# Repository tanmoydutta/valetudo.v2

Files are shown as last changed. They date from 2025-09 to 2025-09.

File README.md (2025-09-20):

# Valetudo V2 - a CR2032 powered Temperature and Humidity sensor with ePaper display
Valetudo V2 has been an improvement on the previous version to add an onboard SEN40 Temperature / Humidity Sensor. This design also includes adjustments to the Battery circuit as well as support for different variants of the ePaper Display.

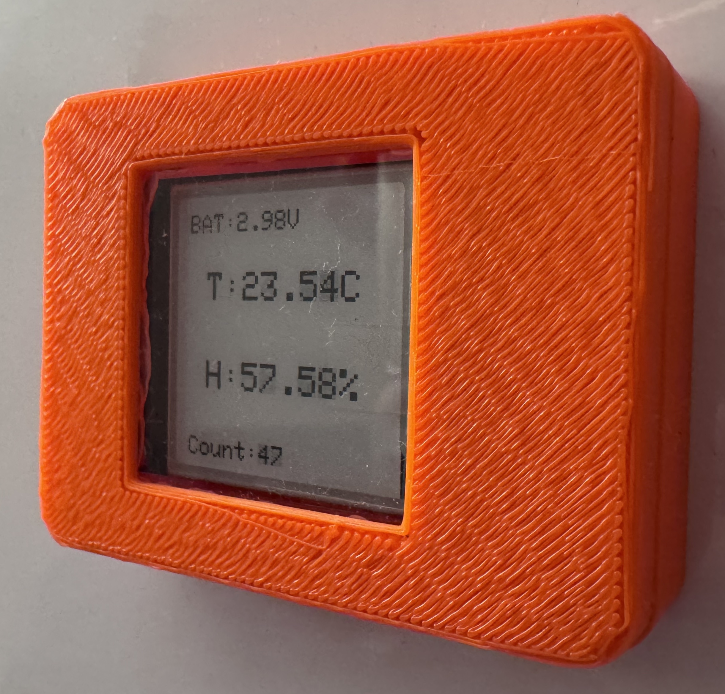
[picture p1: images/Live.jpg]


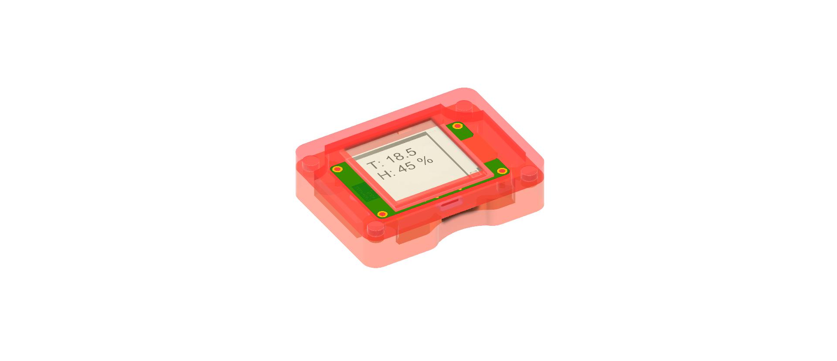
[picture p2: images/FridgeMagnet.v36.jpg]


The form factor has remained the same for the new PCB and some of the components have been slightly reoriented to make room for the new electronics. Powered by the same CR2032 coin cell with firmware enhancements to improve battery life.

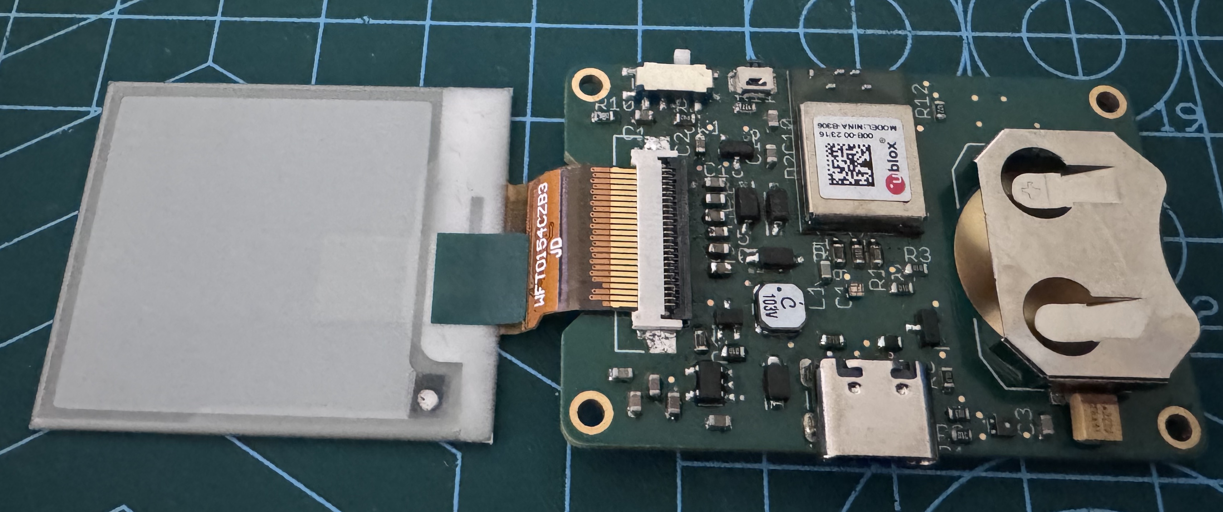
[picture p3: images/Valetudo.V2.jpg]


The body and the lid of the enclosure are embedded with magnetic snap-on feature with an acrylic viewing window for protection for the epaper display. 

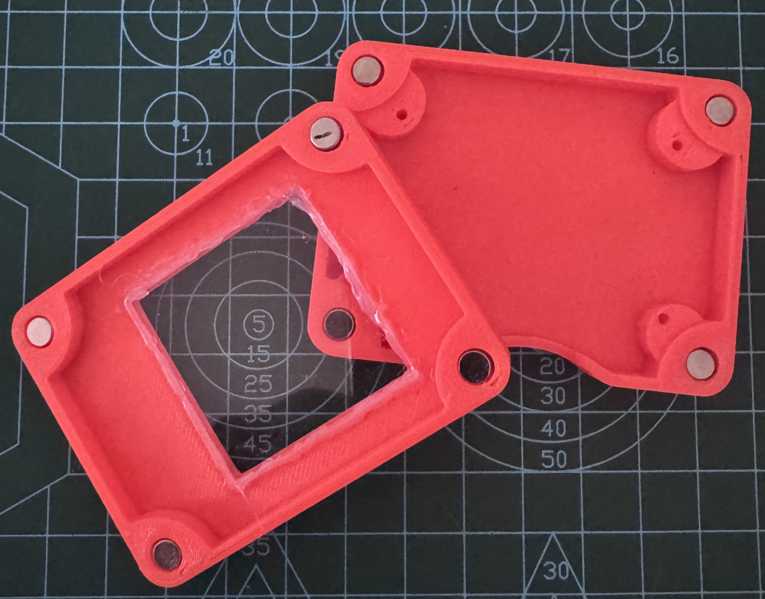
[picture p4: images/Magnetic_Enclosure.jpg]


The enclosure is now fitted with two large 12x3 mm neodymium magnets for better strength to remain stuck with a metallic surface like a refrigerator or a whiteboard.
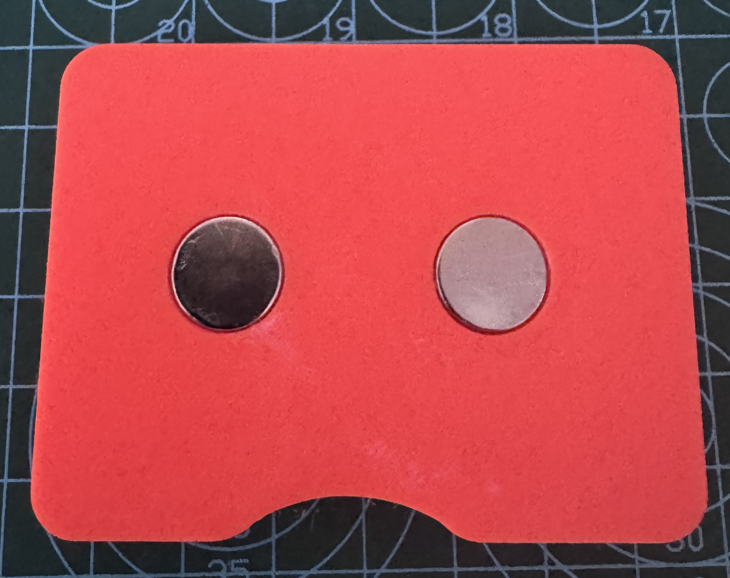
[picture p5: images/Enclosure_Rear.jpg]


This project is certified as Open Source Hardware - 
<p align="center">
  <a href="https://certification.oshwa.org/nl000034.html">
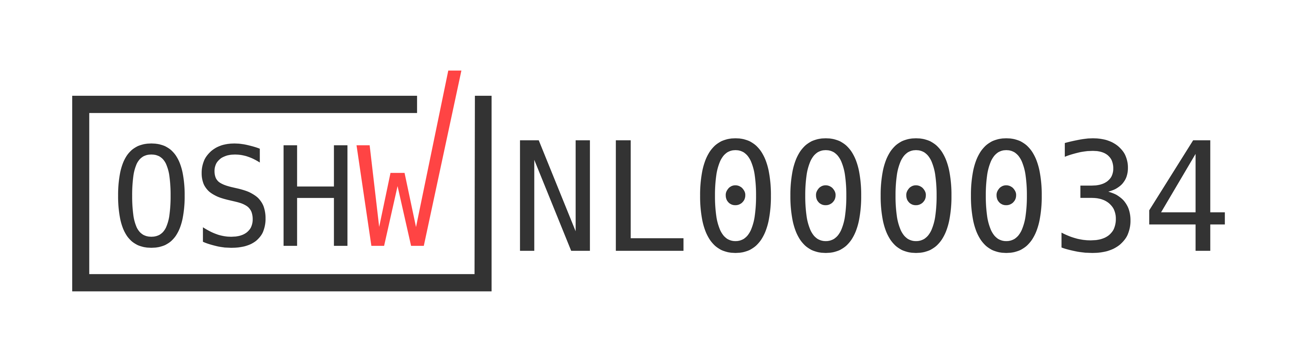
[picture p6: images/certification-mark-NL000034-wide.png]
OSHWA OSHWA Certification
    
  </a>
</p>

License information on the hardware and software and documentation is as follows -



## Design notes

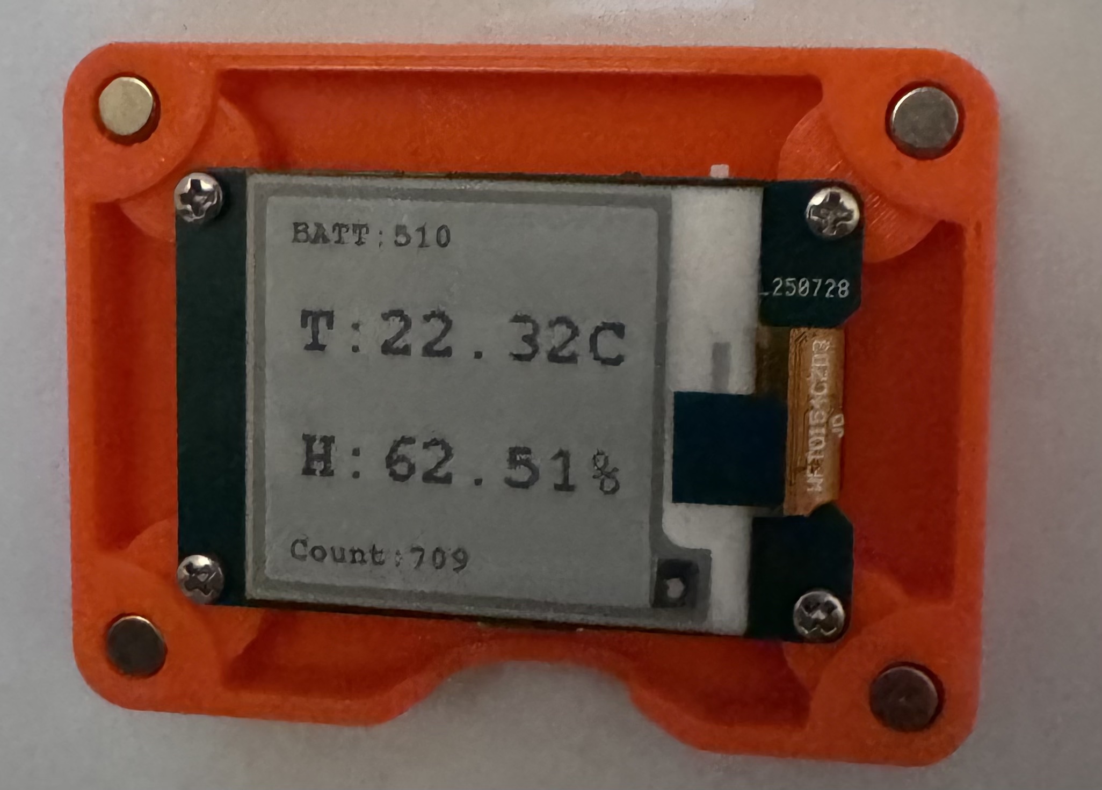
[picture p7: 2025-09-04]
images/InAction.jpg

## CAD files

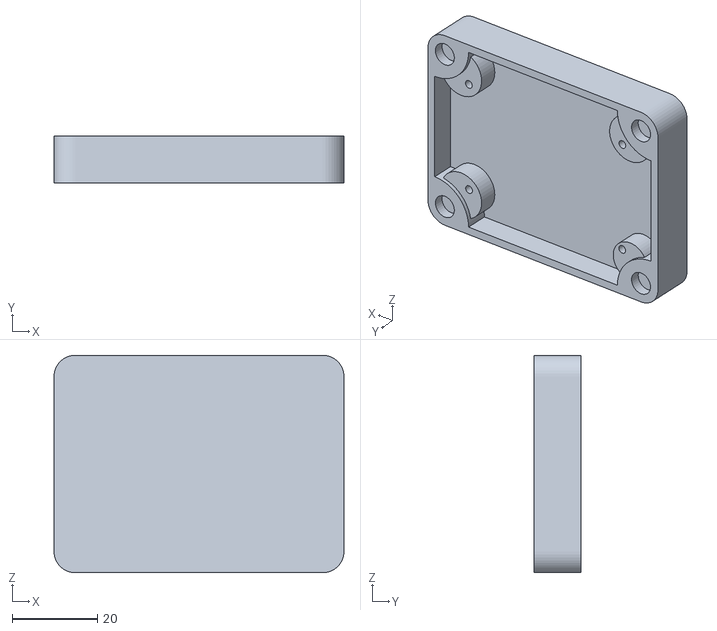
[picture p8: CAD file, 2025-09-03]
3D_Models/Magnetic_Bottom.stl
68.0 x 11.0 x 51.0

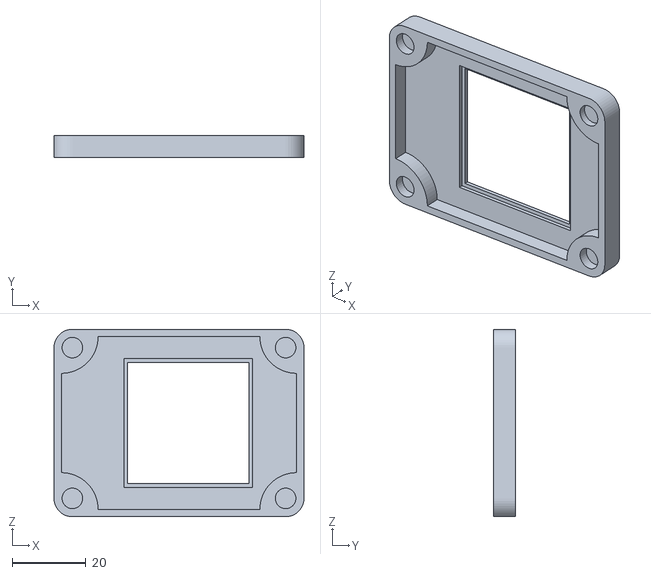
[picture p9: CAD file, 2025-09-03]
3D_Models/Magnetic_Top.stl
68.0 x 6.00 x 51.0

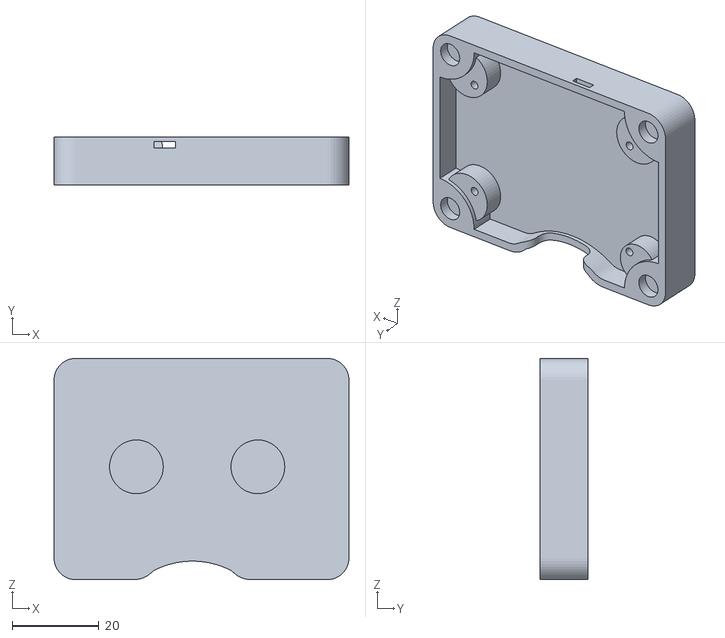
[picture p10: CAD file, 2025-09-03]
3D_Models/Magnetic_Bottom_Hollow_Bent.stl
68.0 x 11.0 x 51.0

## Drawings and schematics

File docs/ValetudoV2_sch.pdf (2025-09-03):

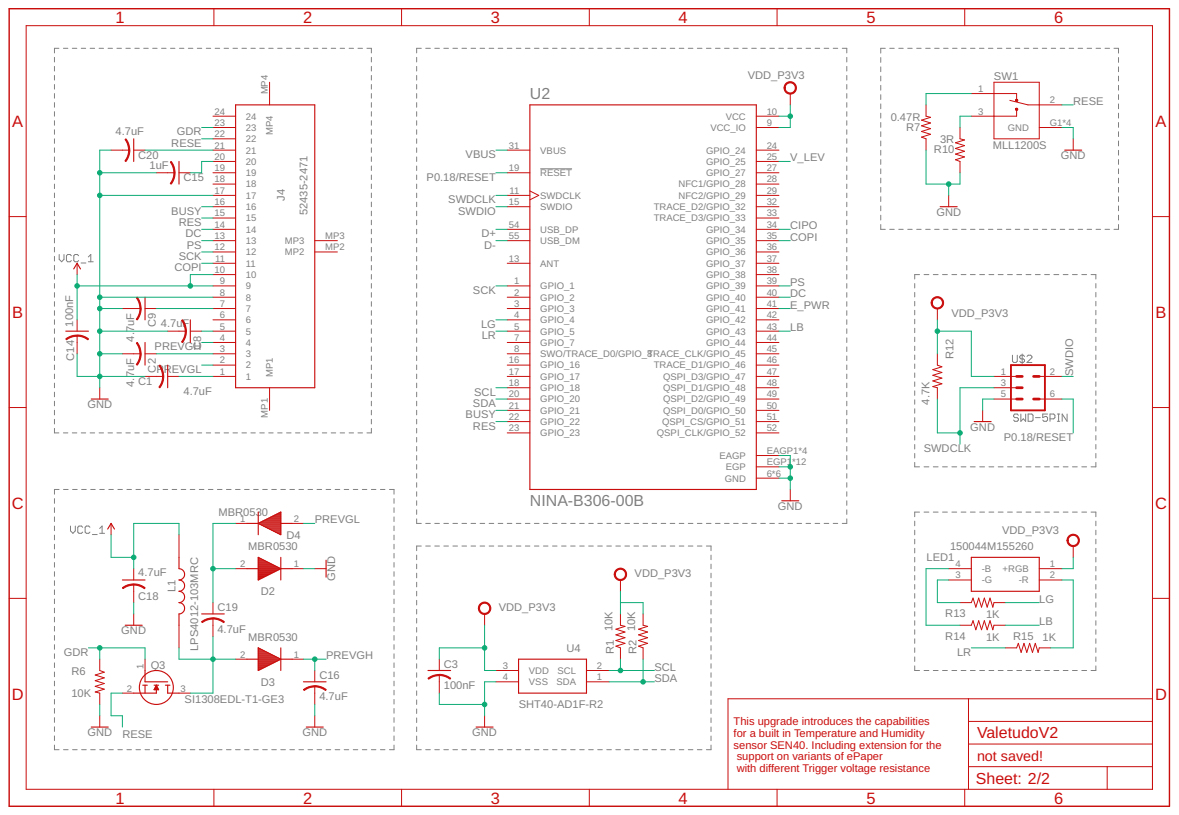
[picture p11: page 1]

This upgrade introduces the capabilities for a built in Temperature and Humidity sensor SEN40. Including extension for the

Sheet:

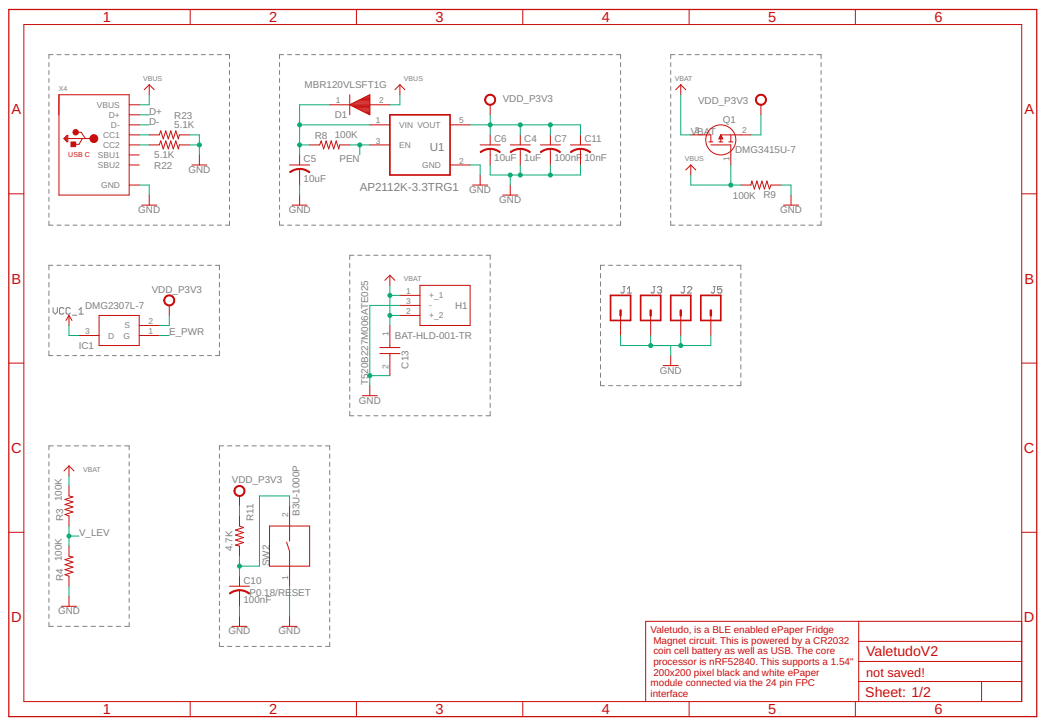
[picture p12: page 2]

Valetudo, is a BLE enabled ePaper Fridge Magnet circuit. This is powered by a CR2032 coin cell battery as well as USB. The core processor is nRF52840. This supports a 1.54" 200x200 pixel black and white ePaper module connected via the 24 pin FPC interface

Sheet: 1/2

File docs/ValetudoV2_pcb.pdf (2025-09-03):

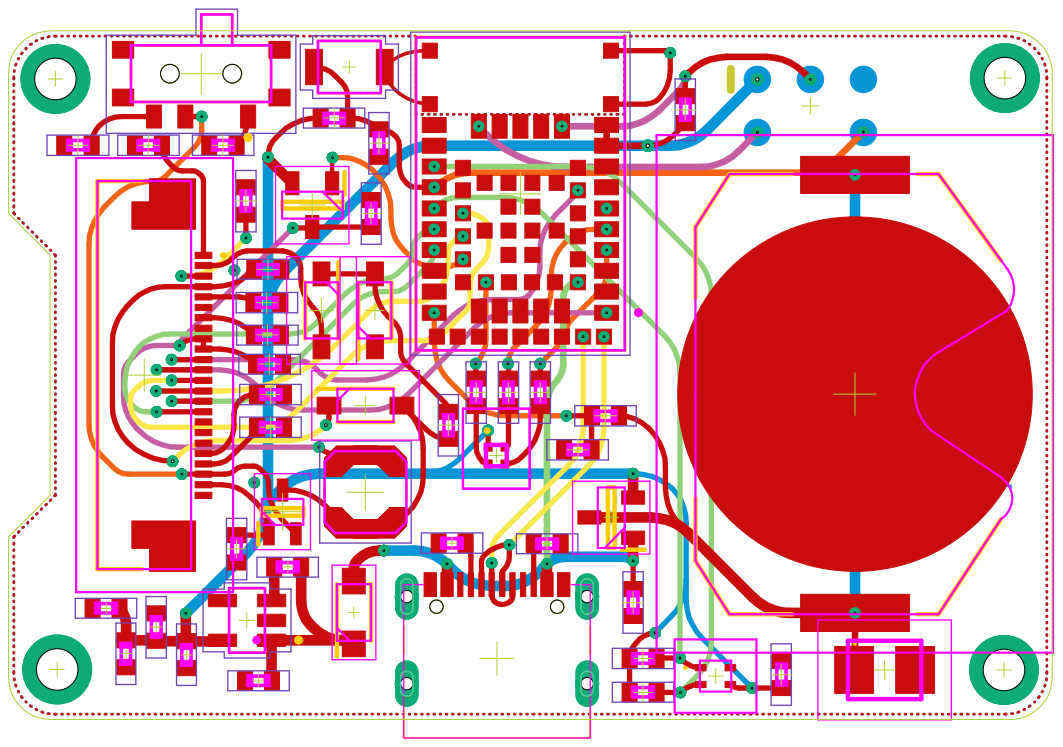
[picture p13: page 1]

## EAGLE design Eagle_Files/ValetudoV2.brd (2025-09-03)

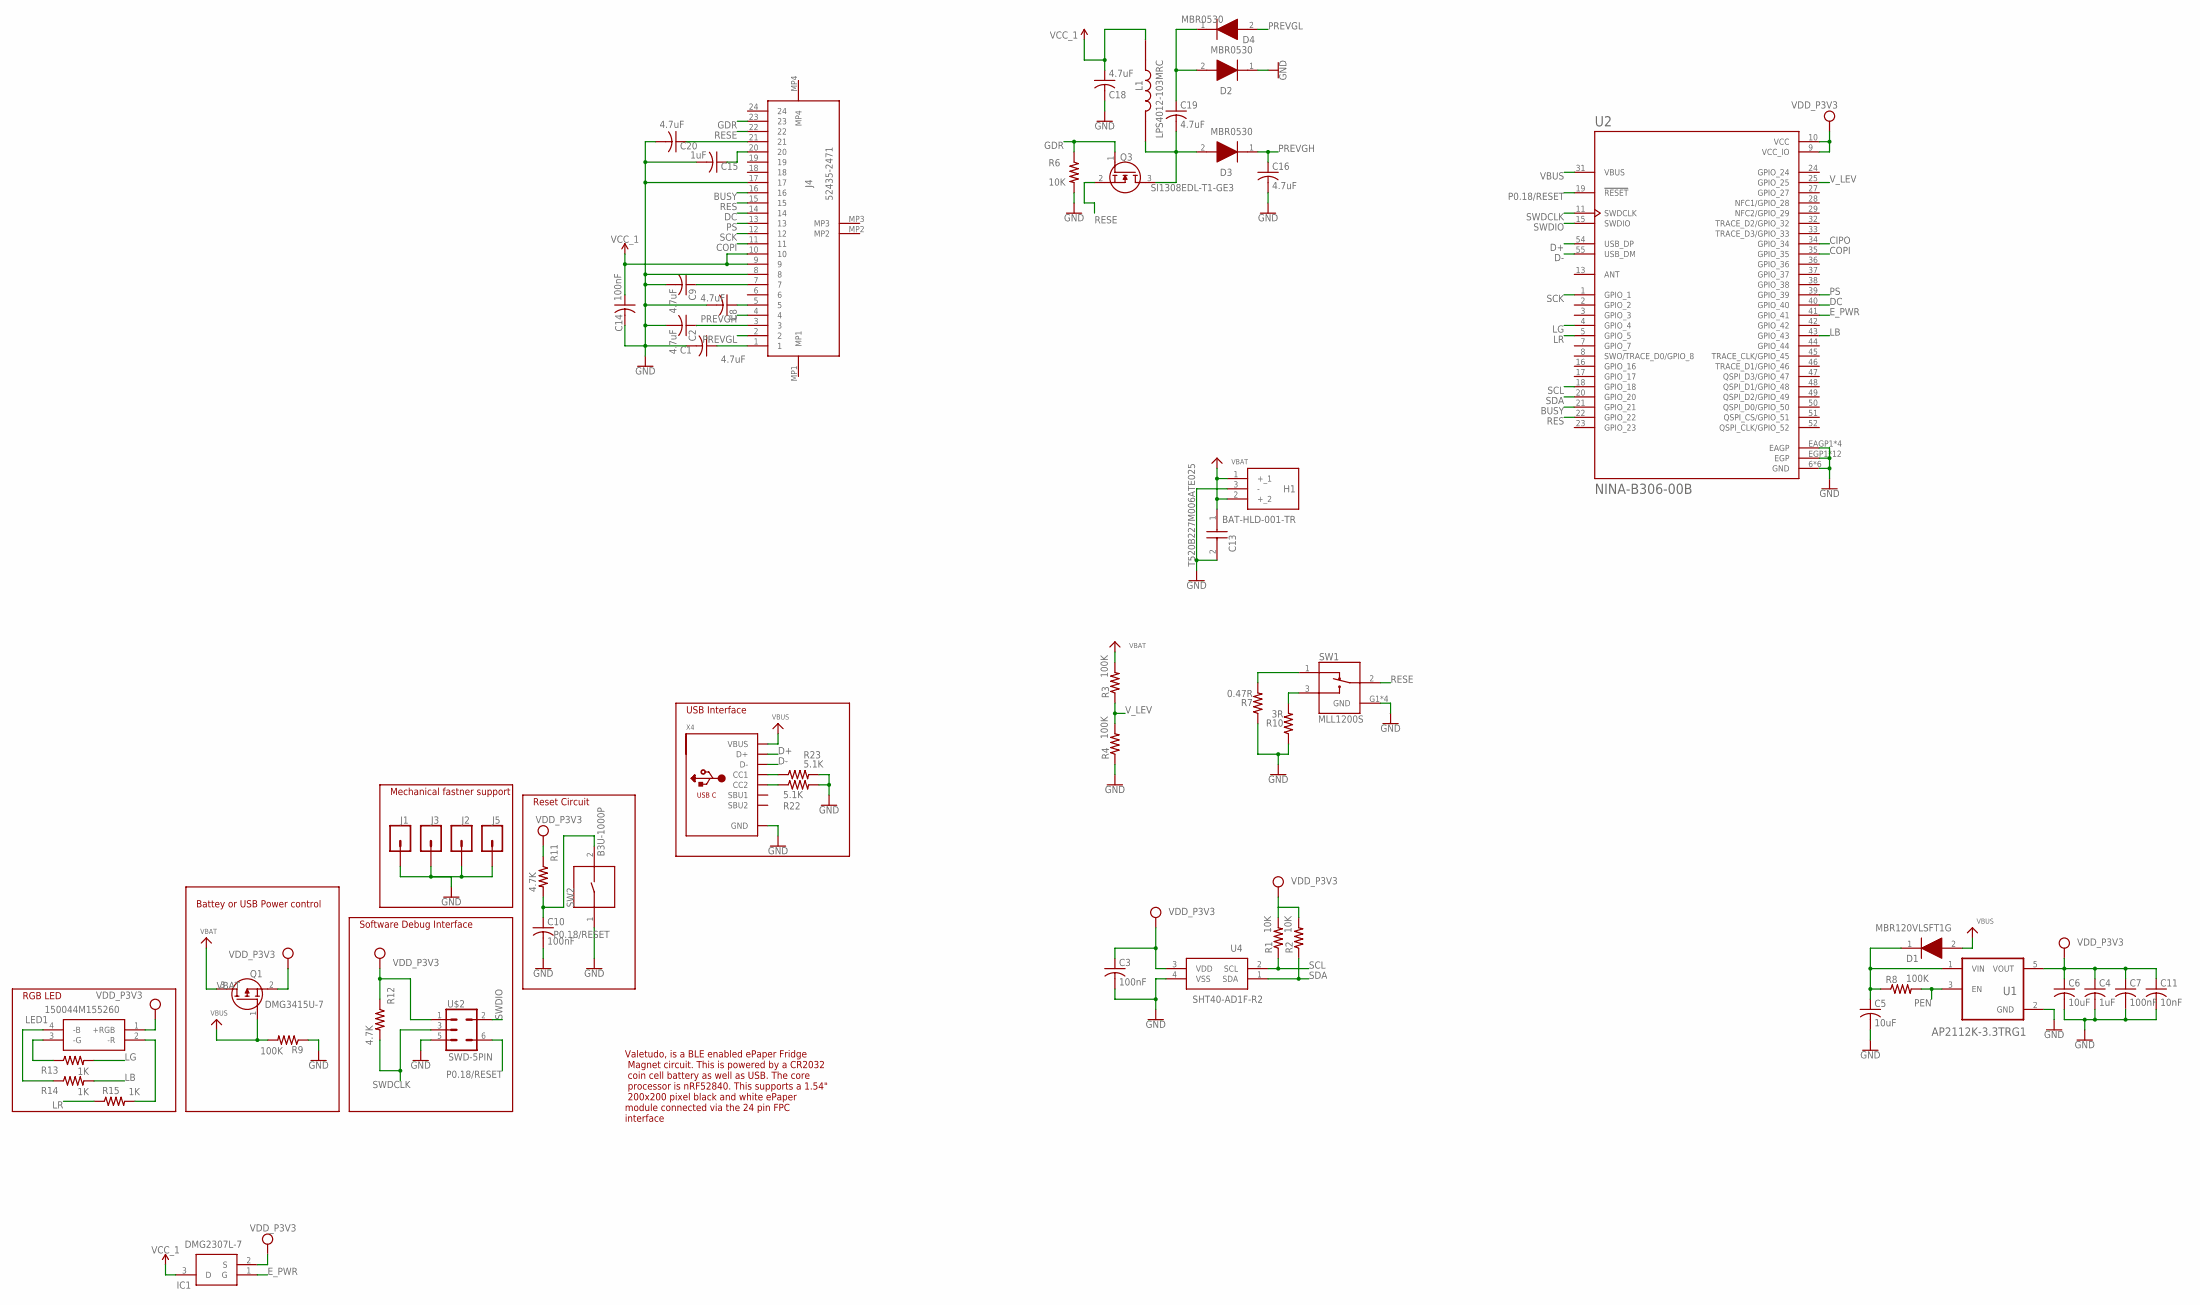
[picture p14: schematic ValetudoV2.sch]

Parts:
C1, C2, C8, C9, C16, C18, C19, C20: 4.7uF; C0402
C3, C7, C10, C14: 100nF; C0402
C4, C15: 1uF; C0402
C5, C6: 10uF; C0402
C11: 10nF; C0402
C13: T520B227M006ATE025; T520B
D1: MBR120VLSFT1G; SODFL3616X98N
D2, D3, D4: MBR0530; SOD3716X135N
H1: BAT-HLD-001-TR; BATHLD001TR
IC1: DMG2307L-7; SOT96P240X110-3N
J1, J2, J3, J5: CONN_01PTH_2MM; 1X01_2MM
J4: 52435-2471; 524352471
L1: LPS4012-103MRC; IND_LPS4012-103MRC
LED1: 150044M155260
Q1: DMG3415U-7; SOT96P240X100-3N
Q3: SI1308EDL-T1-GE3; SOT65P210X110-3N
R1, R2, R6: 10K; R0402
R3, R4, R8, R9: 100K; R0402
R7: 0.47R; R0402
R10: 3R; R0402
R11, R12: 4.7K; R0402
R13, R14, R15: 1K; R0402
R22, R23: 5.1K; R0402
SW1: MLL1200S; SW_MLL1200S
SW2: B3U-1000P; SW_B3U-1000P
U1: AP2112K-3.3TRG1; SOT95P285X140-5N
U2: NINA-B306-00B; XCVR_NINA-B306-00B
U4: SHT40-AD1F-R2; SHT40AD1FR2
U$2: SWD-5PIN; PAD_05_03X2_TP_NO4
X4: MICROBUILDER_USB_C; MICROBUILDER_USB_C_CUSB31-CFM2AX-01-X

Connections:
BUSY: J4.16, U2.21 (GPIO_21)
CIPO: U2.34 (GPIO_34)
COPI: J4.11, U2.35 (GPIO_35)
D+: U2.54 (USB_DP), X4.A6 (D+), X4.B6 (D+)
D-: U2.55 (USB_DM), X4.A7 (D-), X4.B7 (D-)
DC: J4.14, U2.40 (GPIO_40)
E_PWR: IC1.1 (G), U2.41 (GPIO_41)
GDR: J4.23, Q3.1 (G), R6.1
GND: C1.2, C2.2, C3.2, C4.2, C5.2, C6.2, C7.2, C8.2, C9.2, C10.2, C11.2, C13.2 (-), C14.2, C15.2, C16.2, C18.2, C20.2, D2.1 (K), H1.3 (-), J1.1, J2.1, J3.1, J4.8, J4.17, J5.1, R4.1, R6.2, R7.1, R9.1, R10.1, R22.2, R23.2, SW1.G1 (GND), SW1.G2 (GND), SW1.G3 (GND), SW1.G4 (GND), SW2.1, U1.2 (GND), U2.6 (GND), U2.12 (GND), U2.14 (GND), U2.26 (GND), U2.30 (GND), U2.53 (GND), U2.EAGP1 (EAGP), U2.EAGP2 (EAGP), U2.EAGP3 (EAGP), U2.EAGP4 (EAGP), U2.EGP1 (EGP), U2.EGP2 (EGP), U2.EGP3 (EGP), U2.EGP4 (EGP), U2.EGP5 (EGP), U2.EGP6 (EGP), U2.EGP7 (EGP), U2.EGP8 (EGP), U2.EGP9 (EGP), U2.EGP10 (EGP), U2.EGP11 (EGP), U2.EGP12 (EGP), U4.4 (VSS), U$2.5, X4.A1B12 (GND), X4.B1A12 (GND)
LB: R14.2, U2.43 (GPIO_43)
LG: R13.2, U2.4 (GPIO_4)
LR: R15.1, U2.5 (GPIO_5)
unnamed: LED1.4 (-B), R14.1
unnamed: LED1.3 (-G), R13.1
unnamed: LED1.2 (-R), R15.2
unnamed: R7.2, SW1.1
unnamed: C1.1, J4.1
unnamed: C19.1, D2.2 (A), D4.1 (K)
unnamed: R22.1, X4.B5 (CC2)
unnamed: C2.1, J4.3
unnamed: R23.1, X4.A5 (CC1)
unnamed: C5.1, D1.1 (K), R8.1, U1.1 (VIN)
unnamed: C19.2, D3.2 (A), L1.2, Q3.3 (D)
unnamed: C8.1, J4.5
unnamed: R10.2, SW1.3
unnamed: C9.1, J4.7
unnamed: C15.1, J4.20
unnamed: C20.1, J4.21
P0.18/RESET: C10.1, R11.2, SW2.2, U2.19 (!RESET), U$2.6
PEN: R8.2, U1.3 (EN)
PREVGH: C16.1, D3.1 (K), J4.4
PREVGL: D4.2 (A), J4.2
PS: J4.13, U2.39 (GPIO_39)
RES: J4.15, U2.22 (GPIO_22)
RESE: J4.22, Q3.2 (S), SW1.2
SCK: J4.12, U2.1 (GPIO_1)
SCL: R1.1, U2.18 (GPIO_18), U4.2 (SCL)
SDA: R2.1, U2.20 (GPIO_20), U4.1 (SDA)
SWDCLK: R12.2, U2.11 (SWDCLK), U$2.3
SWDIO: U2.15 (SWDIO), U$2.2
VBAT: C13.1 (+), H1.1 (+_1), H1.2 (+_2), Q1.3 (D), R3.2
VBUS: D1.2 (A), Q1.1 (G), R9.2, U2.31 (VBUS), X4.A4B9 (VBUS), X4.B4A9 (VBUS)
VCC: C3.1, C4.1, C6.1, C7.1, C11.1, IC1.2 (S), LED1.1 (+RGB), Q1.2 (S), R1.2, R2.2, R11.1, R12.1, U1.5 (VOUT), U2.9 (VCC_IO), U2.10 (VCC), U4.3 (VDD), U$2.1
VCC_1: C14.1, C18.1, IC1.3 (D), J4.9, J4.10, L1.1
V_LEV: R3.1, R4.2, U2.25 (GPIO_25)

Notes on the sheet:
Battey or USB Power control
Reset Circuit
USB Interface
Software Debug Interface
Valetudo, is a BLE enabled ePaper Fridge Magnet circuit. This is powered by a CR2032 coin cell battery as well as USB. The core processor is nRF52840. This supports a 1.54" 200x200 pixel black and white ePaper module connected via the 24 pin FPC interface
RGB LED
Mechanical fastner support

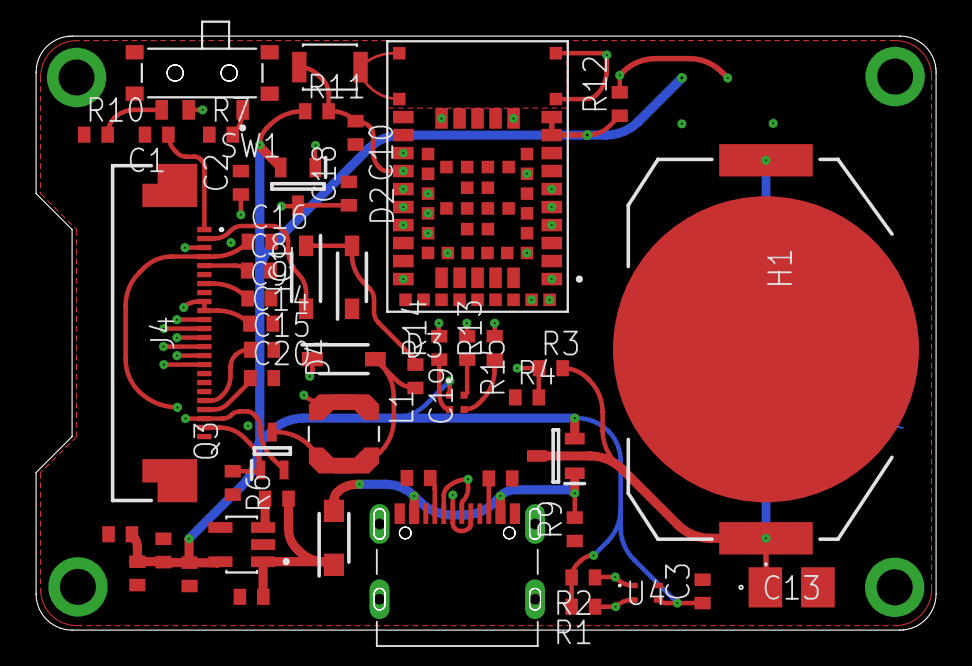
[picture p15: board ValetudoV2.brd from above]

Board: 6 copper layers, 50.0 x 33.0 mm, 56 parts (1 on the bottom side), 44 nets.

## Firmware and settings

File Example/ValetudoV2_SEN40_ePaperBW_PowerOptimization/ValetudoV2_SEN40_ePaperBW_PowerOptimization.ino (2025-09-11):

#define ENABLE_GxEPD2_GFX 0

#include <GxEPD2_BW.h>

#include "Adafruit_SHT4x.h"


#include <Fonts/FreeMonoBold9pt7b.h>
#include <Fonts/FreeMonoBold12pt7b.h>

Adafruit_SHT4x sht4 = Adafruit_SHT4x();

//GxEPD2_BW<GxEPD2_154, GxEPD2_154::HEIGHT> display(GxEPD2_154(/*CS=D8*/ D2, /*DC=D3*/ D4, /*RST=D4*/ D5, /*BUSY=D2*/ D3)); // GDEP015OC1 200x200, IL3829, no longer available
GxEPD2_BW<GxEPD2_154_M09, GxEPD2_154_M09::HEIGHT> display(GxEPD2_154_M09(/*CS=D8*/ D2, /*DC=D3*/ D4, /*RST=D4*/ D5, /*BUSY=D2*/ D3)); // GDEW0154M09 200x200, JD79653A --Good Display
//GxEPD2_3C<GxEPD2_266c, GxEPD2_266c::HEIGHT> display(GxEPD2_266c(/*CS=D8*/ D2, /*DC=D3*/ D4, /*RST=D4*/ D5, /*BUSY=D2*/ D3)); // GDEY0266Z90 152x296, SSD1680 -- Red Black White
int counter = 0;
int refreshCounter = 0;

void setup()
{  
  Serial.begin(115200);
  Serial.println();
  Serial.println("setup");
  pinMode(D6, OUTPUT);
  digitalWrite(D6, LOW);

  pinMode(LEDR, OUTPUT);
  pinMode(LEDG, OUTPUT);
  pinMode(LEDB, OUTPUT);
  
  
  digitalWrite(LEDR, HIGH);
  digitalWrite(LEDG, HIGH);
  digitalWrite(LEDB, HIGH);

  delay(100);

  Serial.println("Adafruit SHT4x test");
  if (! sht4.begin()) {
    Serial.println("Couldn't find SHT4x");
    while (1) delay(1);
  }
  Serial.println("Found SHT4x sensor");
  Serial.print("Serial number 0x");
  Serial.println(sht4.readSerial(), HEX);

  // You can have 3 different precisions, higher precision takes longer
  sht4.setPrecision(SHT4X_LOW_PRECISION);

  sht4.setHeater(SHT4X_NO_HEATER);

  display.init(115200); // default 10ms reset pulse, e.g. for bare panels with DESPI-C02
  //display.init(115200, true, 2, false); // USE THIS for Waveshare boards with "clever" reset circuit, 2ms reset pulse
  //display.init(115200, true, 10, false, SPIn, SPISettings(4000000, MSBFIRST, SPI_MODE0)); // extended init method with SPI channel and/or settings selection
 /* if (display.pages() > 1)
  {
    delay(100);
    Serial.print("pages = "); Serial.print(display.pages()); Serial.print(" page height = "); Serial.println(display.pageHeight());
    delay(1000);
  }*/
  display.clearScreen(); //return;
  // first update should be full refresh
  //display.powerOff();
  delay(500);
  

}

void loop()
{
  //deepSleepTest();
  viewSensorData();
}

void viewSensorData() 
{
  sensors_event_t humidity, temp;
  float battLevel= analogRead(A0);
  
  battLevel *= 2;    // we divided by 2, so multiply back
  battLevel *= 3.0;  // Multiply by 3.6V, our reference voltage
  battLevel /= 1024; // convert to voltage
  Serial.print("VBat: " ); Serial.println(battLevel);

  //uint32_t timestamp = millis();
  sht4.getEvent(&humidity, &temp);// populate temp and humidity objects with fresh data
  //timestamp = millis() - timestamp;

  Serial.print("Temperature: "); Serial.print(temp.temperature); Serial.println(" degrees C");
  Serial.print("Humidity: "); Serial.print(humidity.relative_humidity); Serial.println("% rH");

  //Serial.print("Read duration (ms): ");
  //Serial.println(timestamp);
  
  
  //Serial.println("deepSleepTest");
  const char temperatureText[] = "T:13.06C";
  const char humidityText[] = "H:40.00%";
  const char battText[] = "BAT:0.00V";
  const char countText[] = "Count:99999";

  digitalWrite(D6, LOW);
  //display.init(115200);
  
  if (refreshCounter > 50) {
    refreshCounter = 0;
    display.clearScreen();
  }

  display.setRotation(1);
  //display.setFont(&FreeMonoBold9pt7b);
  if (display.epd2.WIDTH < 104) display.setFont(0);
  display.setTextColor(GxEPD_BLACK);
  display.setTextSize(3);
  int16_t tbx, tby; uint16_t tbw, tbh;
  // center text
  
  display.getTextBounds(temperatureText, 0, 0, &tbx, &tby, &tbw, &tbh);
  uint16_t wx = (display.width() - tbw) / 2;
  uint16_t wy = ((display.height() / 3) - tbh / 2) - tby; // y is base line!
  display.setPartialWindow(wx, wy, tbw, tbh);
  display.firstPage();
  do
  {
    display.fillScreen(GxEPD_WHITE);
    display.setCursor(wx, wy);
    display.print("T:");
    display.print(temp.temperature);
    display.print("C");    
  }while (display.nextPage());

  display.getTextBounds(humidityText, 0, 0, &tbx, &tby, &tbw, &tbh);
  uint16_t fx = (display.width() - tbw) / 2;
  uint16_t fy = ((display.height() * 2 / 3) - tbh / 2) - tby; // y is base line!
  display.setPartialWindow(fx, fy, tbw, tbh);
  display.firstPage();
  do
  {
    display.fillScreen(GxEPD_WHITE);
    display.setCursor(fx, fy);
    display.print("H:");
    display.print(humidity.relative_humidity);
    display.print("%");
  } while (display.nextPage());

  //Battery Voltage
  display.setTextSize(2);
  display.getTextBounds(battText, 0, 0, &tbx, &tby, &tbw, &tbh);
  uint16_t gx = 10; //(display.width() - tbw) / 2;
  uint16_t gy = 10;
  display.setPartialWindow(gx, gy, tbw, tbh);
  display.firstPage();
  do
  {
    display.fillScreen(GxEPD_WHITE);
    display.setCursor(gx, gy); //display.setCursor(10, 20);
    display.print("BAT:");
    display.print(battLevel);display.print("V");

  } while (display.nextPage());

  //Count
  display.getTextBounds(countText, 0, 0, &tbx, &tby, &tbw, &tbh);
  uint16_t hx = 10;
  uint16_t hy = 180;
  display.setPartialWindow(hx, hy, tbw, tbh);
  display.firstPage();
  do
  {
    display.fillScreen(GxEPD_WHITE);

    display.setCursor(hx, hy); //display.setCursor(10, 190);
    display.print("Count:");
    display.print(++counter);
  } while (display.nextPage());

  //display.hibernate();
  display.powerOff();

  digitalWrite(D6, HIGH);
  /*digitalWrite(LEDR, HIGH);
  digitalWrite(LEDG, HIGH);
  digitalWrite(LEDB, LOW);

  delay(50);

  digitalWrite(LEDR, HIGH);
  digitalWrite(LEDG, HIGH);
  digitalWrite(LEDB, HIGH);*/
  refreshCounter++;

  delay(60000);
  delay(60000);
  delay(60000);
  delay(60000);
  delay(60000);
  delay(60000);
  delay(60000);
  delay(60000);
  delay(60000);
  delay(60000);

  delay(60000);
  delay(60000);
  delay(60000);
  delay(60000);
  delay(60000);
  delay(60000);
  delay(60000);
  delay(60000);
  delay(60000);
  delay(60000);

  delay(60000);
  delay(60000);
  delay(60000);
  delay(60000);
  delay(60000);
  delay(60000);
  delay(60000);
  delay(60000);
  delay(60000);
  delay(60000);

}

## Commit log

2025-09-03 Adding structure
    [ValetudoV2.brd, ValetudoV2.sch]
2025-09-03 Added 3D files documentation and images
    [Magnetic_Bottom.stl, Magnetic_Bottom_Hollow_Bent.stl, Magnetic_Top.stl]
2025-09-03 Added schematics
2025-09-11 Adding source code for the sample program

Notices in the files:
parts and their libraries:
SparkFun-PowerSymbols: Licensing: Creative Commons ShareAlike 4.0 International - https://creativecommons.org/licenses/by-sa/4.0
